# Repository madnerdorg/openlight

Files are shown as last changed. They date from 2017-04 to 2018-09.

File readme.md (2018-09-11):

[Français](https://madnerdorg.github.io/openlight/readme.fr)

Libre Connect   
[Download Openlight](https://github.com/madnerdorg/openlight/archive/master.zip) /  [LibreConnect](https://madnerdorg.github.io/libreconnect/) / [Source](https://github.com/madnerdorg/openlight)

- [What is OpenLight](#what-is-openlight)
- [Commands](#commands)
- [Applications](#applications)
- [How to build openlight](#how-to-build-openlight)

# What is OpenLight
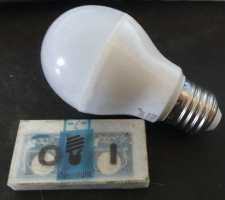
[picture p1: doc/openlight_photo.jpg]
openlight_photo
     
Openlight is an open source alternative for milight gateway based on an arduino nano (clone).     
Based on Henryk Plötz research : [https://hackaday.io/project/5888-reverse-engineering-the-milight-on-air-protocol](https://hackaday.io/project/5888-reverse-engineering-the-milight-on-air-protocol)

Milight bulbs are not controlled using WIFI, it uses its own protocol on **2.4Ghz**.     
openlight Routing      
Our arduino will directly control the light bulbs using **nrf24l01+** radio modules without **using the WIFI gateway**.

Tactile switchs are not mandatory, you can use it to turn on/off a lamp.      
You need to add the code of your lamp in the code, last hexadecimal values will be ignored as it is updated incrementally:     
```
int on [7] = { 0x00, 0x00, 0x00 ,0x00, 0x00, 0x00, 0x01};
int off [7] = { 0x00, 0x00, 0x00 ,0x00, 0x00, 0x00, 0x01};
```
# Commands
/info : display name:port 
```
openlight:42003         
```
When a code is received it will be displayed as 
```
0x00, 0x00, 0x00 ,0x00, 0x00, 0x00, 0x01
```
Enter a previously received code to send it 
```
0x00,0x00,0x00,0x00,0x01,0x03,0x00
``` 
# How to build openlight
* Check http://pdf.libre.ovh for more information.

## Upload
* Copy **arduino/libraries** into your arduino sketchbooks
* Upload **arduino/openlight_gateway/openlight_gateway.ino**

## Components
* 1 Arduino nano (ch340g): 2.50€    
* 1 nrf24l01+ (radio module) : 1€    
* 2 Tactiles switchs : 2€   
> Cost : 5.50€    

## Wiring
**nrf modules use 3.3V not 5V, pins are 5v tolerant**

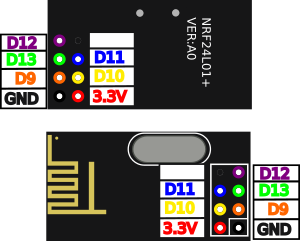
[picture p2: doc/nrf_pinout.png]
nrf_pinout


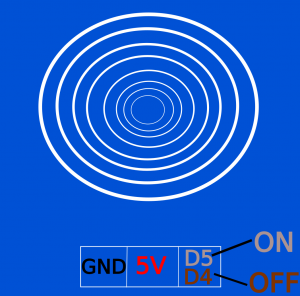
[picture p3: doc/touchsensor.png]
touchsensor


```
NRF
D9 : orange
D10 : yellow
D11 : blue
D12 : purple
D13 : green
3.3V: red

SWITCHS
D4 OFF SIG
D5 ON SIG
5V: VCC
```

# Licences

## openlight.ino
* Author : Rémi Sarrailh (madnerd.org)
* Licence : MIT 

## openmili
* Author : Henryk Plötz
* Licence : GPLv3
* Link: [https://github.com/henryk/openmili](https://github.com/henryk/openmili)

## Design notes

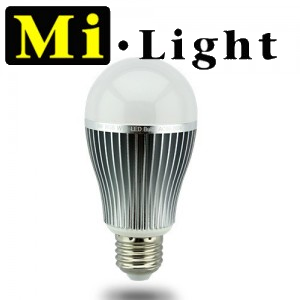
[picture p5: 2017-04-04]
doc/milight.png

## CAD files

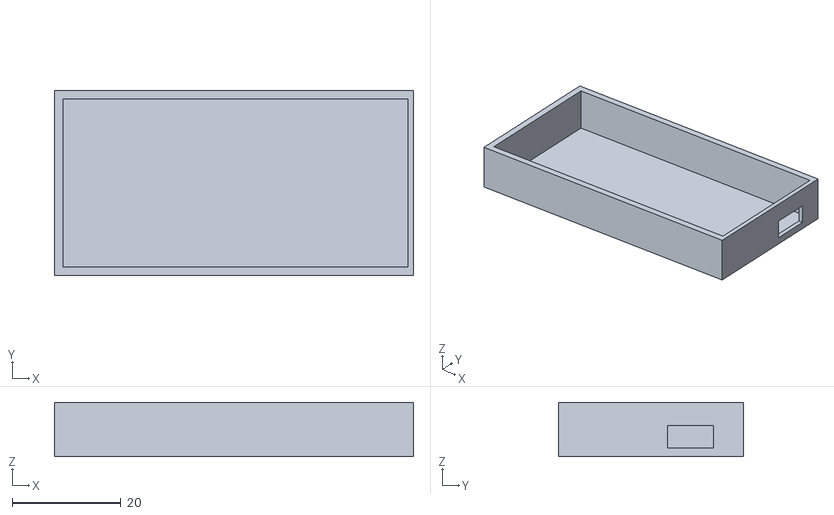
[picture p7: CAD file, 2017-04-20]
stl/openlight_remote_A.stl
66.0 x 34.0 x 10.0

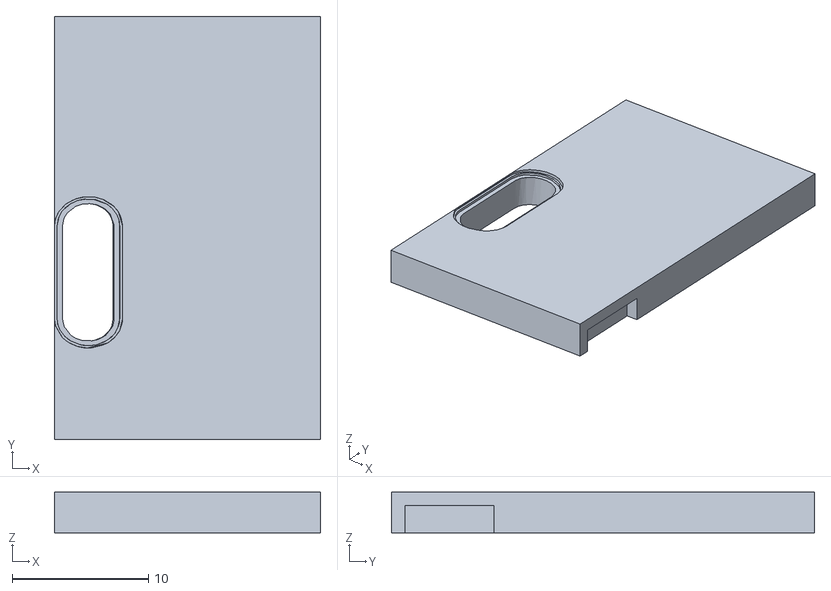
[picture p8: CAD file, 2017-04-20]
stl/openlight_remote_B.stl
19.5 x 31.0 x 3.00

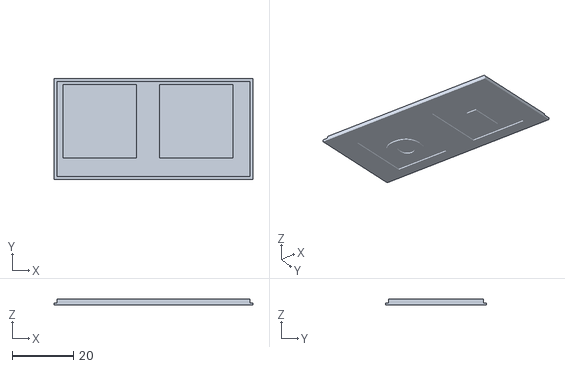
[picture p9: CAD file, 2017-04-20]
stl/openlight_remote_C.stl
65.0 x 33.0 x 2.00

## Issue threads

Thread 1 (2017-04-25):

Case need to be improved

maditnerd, 2017-04-25:
The case doesn't close properly without help from adhesive paste (blu-tack/patafix)

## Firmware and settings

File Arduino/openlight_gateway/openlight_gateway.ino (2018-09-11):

//Openlight : Milight Serial Gateway
//Based on https://hackaday.io/project/5888-reverse-engineering-the-milight-on-air-protocol
// Remi Sarrailh madnerd.org : MIT https://github.com/madnerdorg/openlight
// Henryk Plötz : GPLv3 : https://github.com/henryk/openmili

#include <SPI.h>
#include <nRF24L01.h>
#include <RF24.h>

#include "PL1167_nRF24.h"
#include "MiLightRadio.h"
#include "secrets.h"

//Radio
#define CE_PIN 9
#define CSN_PIN 10

RF24 radio(CE_PIN, CSN_PIN);
PL1167_nRF24 prf(radio);
MiLightRadio mlr(prf);
int sequence = 0x01;

//Buttons pinOut
const int OnPin = 2;
const int OffPin = 3;
const int repeat = 10;

const String usb_name = "madnerdorg/openlight";

//Serial string buffer
String readString;

// Serial

//When application asked if this is the correct arduino
void serialCheck() {
  if (readString == "/info") {
    Serial.println(usb_name);
  } else {
    //Serial.println(readString);
    int code[7];
    code[0] = hexToDec(getValue(readString, ',', 0));
    code[1] = hexToDec(getValue(readString, ',', 1));
    code[2] = hexToDec(getValue(readString, ',', 2));
    code[3] = hexToDec(getValue(readString, ',', 3));
    code[4] = hexToDec(getValue(readString, ',', 4));
    code[5] = hexToDec(getValue(readString, ',', 5));
    code[6] = 0x01;
    radioSend(code);
  }
}

//Convert characters sent by serial to string
void serialManager() {
  //Get Serial as a string
  while (Serial.available()) {
    delay(3); // Wait for data

    //Convert to String
    if (Serial.available() > 0) {
      char c = Serial.read();
      readString += c;
    }
  }
}

void setup()
{
  Serial.begin(115200);
  pinMode(OnPin, INPUT_PULLUP);
  pinMode(OffPin, INPUT_PULLUP);
  mlr.begin();
}

void loop()
{
  radioReceive();
  serialManager();

  //If string received
  if (readString.length() > 0) {
    serialCheck();
  }

  //We clean the serial buffer
  readString = "";

  //If ON button pressed send on
  if (!digitalRead(OnPin)) {
    radioSend(on);
  }

  //If OFF button pressed send off
  if (!digitalRead(OffPin)) {
    radioSend(off);
  }

}


void radioReceive() {
  if (mlr.available()) {
    uint8_t packet[7];
    size_t packet_length = sizeof(packet);
    mlr.read(packet, packet_length);

    for (int i = 0; i < packet_length; i++) {
      if (packet[i] < 10) {
        Serial.print("0x0");
      } else {
        Serial.print("0x");
      }
      Serial.print(packet[i], HEX);

      if (i != (packet_length - 1)) {
        Serial.print(",");
      }
    }
    Serial.println();
  }
}

void radioSend(int code [7] ) {
  //Prepare message
  uint8_t outgoingPacket_tmp [7] ;
  for (int i = 0; i < 6; i++)
  {
    outgoingPacket_tmp[i] = (uint8_t)code[i];

    if (code[i] < 10) {
      Serial.print("0x0");
    } else {
      Serial.print("0x");
    }
    Serial.print(code[i], HEX);
    Serial.print(",");
  }

  uint8_t sequence_tmp = (uint8_t)sequence;

  if (sequence_tmp < 10) {
    Serial.print("0x0");
  } else {
    Serial.print("0x");
  }
  Serial.print(sequence_tmp, HEX);
  Serial.println();
  outgoingPacket_tmp[6] = sequence_tmp;

  //Send message
  for (int i = 0; i < repeat; i++) {
    mlr.write(outgoingPacket_tmp, sizeof(outgoingPacket_tmp));
    delay(20);
    sequence++;
    outgoingPacket_tmp[6] = (uint8_t)sequence;
  }
}


//Equivalent of explode in PHP (use for serial commands parsing)
String getValue(String data, char separator, int index) {
  int found = 0;
  int strIndex[] = {0, -1};
  int maxIndex = data.length() - 1;

  for (int i = 0; i <= maxIndex && found <= index; i++) {
    if (data.charAt(i) == separator || i == maxIndex) {
      found++;
      strIndex[0] = strIndex[1] + 1;
      strIndex[1] = (i == maxIndex) ? i + 1 : i;
    }
  }

  return found > index ? data.substring(strIndex[0], strIndex[1]) : "";
}

//https://github.com/benrugg/Arduino-Hex-Decimal-Conversion/blob/master/hex_dec.ino
unsigned int hexToDec(String hexString) {

  unsigned int decValue = 0;
  int nextInt;

  for (int i = 2; i < hexString.length(); i++) {

    nextInt = int(hexString.charAt(i));
    if (nextInt >= 48 && nextInt <= 57) nextInt = map(nextInt, 48, 57, 0, 9);
    if (nextInt >= 65 && nextInt <= 70) nextInt = map(nextInt, 65, 70, 10, 15);
    if (nextInt >= 97 && nextInt <= 102) nextInt = map(nextInt, 97, 102, 10, 15);
    nextInt = constrain(nextInt, 0, 15);

    decValue = (decValue * 16) + nextInt;
  }

  return decValue;
}

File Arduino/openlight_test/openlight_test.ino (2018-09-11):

#include <SPI.h>
#include "nRF24L01.h"
#include <RF24.h>
#include "printf.h"

// SETTINGS
#define CE_PIN 9
#define CSN_PIN 10

RF24 radio(CE_PIN, CSN_PIN);

const int OnPin = 2;
const int OffPin = 3;

void setup()
{
  Serial.begin(57600); //Baudrate for 115200 (when i removed the voltage regulator, serial became unreadable otherwise)
  //Serial.begin(115200); 

  pinMode(OnPin, INPUT_PULLUP);
  pinMode(OffPin, INPUT_PULLUP);
  attachInterrupt(0, ron, CHANGE);
  attachInterrupt(1, roff, CHANGE);
  
  printf_begin();
  Serial.println("----- TEST ------");
  radio.begin();
  radio.printDetails();
  Serial.println("-----------------");
  Serial.println();
  Serial.println("----- RESULT EXAMPLE -----");
  Serial.println("STATUS     = 0x0e RX_DR=0 TX_DS=0 MAX_RT=0 RX_P_NO=7 TX_FULL=0");
  Serial.println("RX_ADDR_P0-1   = 0xe7e7e7e7e7 0xc2c2c2c2c2");
  Serial.println("RX_ADDR_P2-5   = 0xc3 0xc4 0xc5 0xc6");
  Serial.println("TX_ADDR    = 0xe7e7e7e7e7");
  Serial.println("RX_PW_P0-6   = 0x00 0x00 0x00 0x00 0x00 0x00");
  Serial.println("EN_AA    = 0x3f");
  Serial.println("EN_RXADDR  = 0x03");
  Serial.println("RF_CH    = 0x4c");
  Serial.println("RF_SETUP   = 0x07");
  Serial.println("NRF_CONFIG     = 0x0e");
  Serial.println("DYNPD/FEATURE  = 0x00 0x00");
  Serial.println("Data Rate  = 1MBPS");
  Serial.println("Model    = nRF24L01+");
  Serial.println("CRC Length   = 16 bits");
  Serial.println("PA Power   = PA_MAX");
   Serial.println("--------------------");

}

void ron(){
  Serial.println("BUTTON ON");
}

void roff(){
  Serial.println("BUTTON OFF");
}


void loop()
{
}

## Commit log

2017-04-20 Add case
    [openlight_remote_A.stl, openlight_remote_B.stl, openlight_remote_C.stl]
2017-04-20 Lack of hole for usb/nrf in stl files
    [openlight_remote_A.stl, openlight_remote_B.stl]
2017-04-20 Update photo of device
2017-07-05 [Arduino] Add licence/links
2017-07-05 Change folders (stl/arduino)
    [openlight_remote_A.stl, openlight_remote_B.stl, openlight_remote_C.stl]
2017-07-05 [Arduino] Forgot to move platformio.ini
2018-09-11 Update openlight code (add lowpower switch)
